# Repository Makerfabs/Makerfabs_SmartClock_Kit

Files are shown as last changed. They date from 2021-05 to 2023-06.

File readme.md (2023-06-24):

# Makerfabs SmartClock Kit

```c++
/*
Version:        V1.2
Author:            Vincent
Create Date:    2021/4/14
Note:
    2023/5/12 V1.2:Change Weather API.
    2021/5/27 V1.1:Add product link and picture.

*/
```

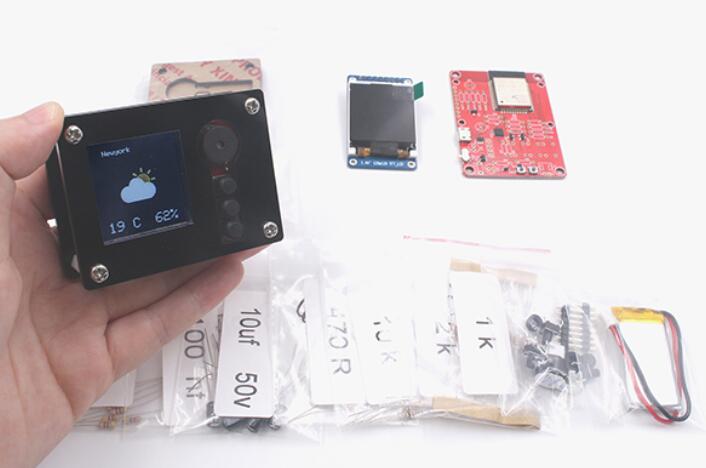
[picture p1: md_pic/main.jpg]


[TOC]

# Makerfabs

[Makerfabs home page](https://www.makerfabs.com/)

[Makerfabs Wiki](https://wiki.makerfabs.com/)

# Makerfabs SmartClock Kit

    It is a kit for starters. After 1~2 hours soldering and assembly, and easy steps to set the WiFi ssid and password by a phone, you will get: 

1. An real-time clock, it will get the world real-time from the Network timing protocol, you can set your local time zone easily 
2. An Alarm clock, with loud noise 
3. An Online world weather forecaster, about the local temperature/weather, you can easily change/alter your address/cities without any re-programming

## Intruduce

Product Link ：[DIY ESP32 SmartClock Kit with Weather Forecasting](https://www.makerfabs.com/diy-esp32-smartclock-kit.html) 

Wiki Link :  [No wiki]() 

Instruction Book : [DIY ESP32 Smart Clock Guide](https://www.makerfabs.com/desfile/files/DIY-ESP32-SmartClock-Guide-V1-5.pdf) 

## Feature

- ESP32 WROOM module: WiFi, Bluetooth, 4MB Flash
- 1.44inch 128*128 color display, ST7735 driver*
- Micro USB interface
- Support Arduino
- 450mAh battery, support charge
- Plug-in components, easy soldering

### Part List

- ESP32 SmartClock Kit Mainboard
- Batch of Capacitors& Resistors/Connectors
- Colorful LCD Module
- Lipo Battery
- Acrylic Boards
- Nuts & screws

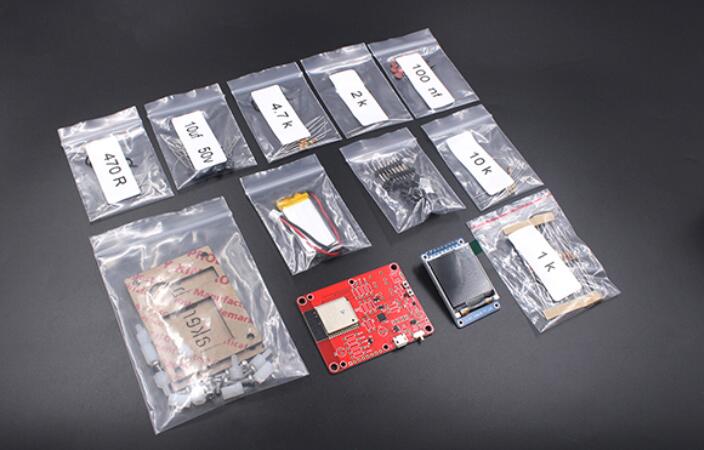
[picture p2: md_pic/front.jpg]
front


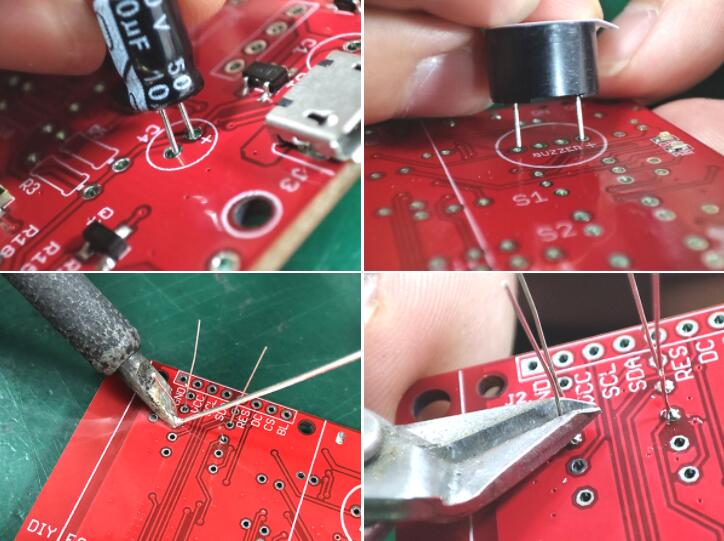
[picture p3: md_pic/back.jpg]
back


# Firmware

## Equipment list

- SmartClock Kit
- Soldering iron

## Compiler Options

**If you have any questions，such as how to install the development board, how to download the code, how to install the library. Please refer to :[Makerfabs_FAQ](https://github.com/Makerfabs/Makerfabs_FAQ)**

- Install board : ESP32 .

- Install library : Adafruit_GFX library.

- Install library : Adafruit_ST7735 library.

- Install library : ArduinoJson library.

- Upload codes, select "ESP32 Dev Module" and "Huge APP"

## How To Use

[How to Make a DIY ESP32 SmartClock with Weather Forecasting](https://www.youtube.com/watch?v=e5g6aSs4Ocg&t=6s)

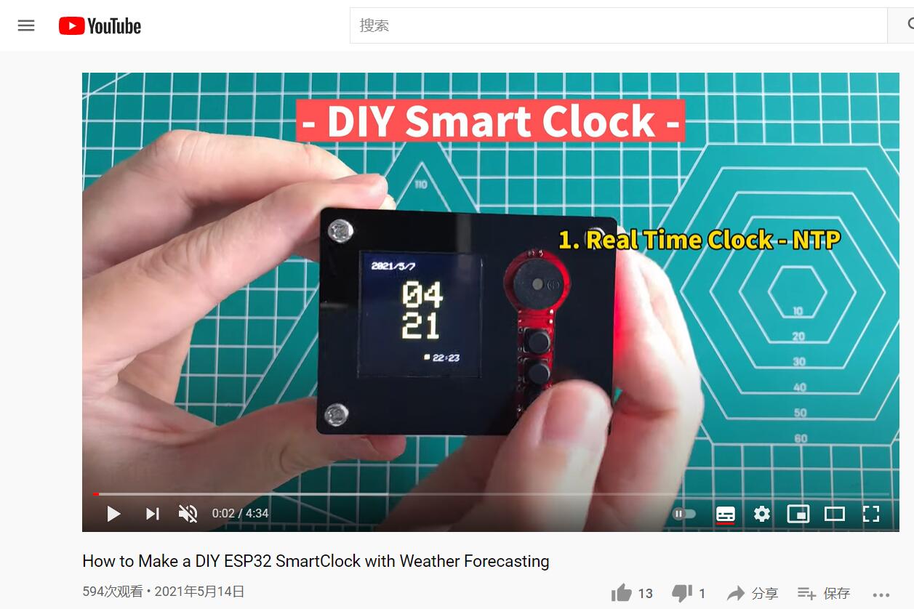
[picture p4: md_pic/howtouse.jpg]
Howtouse


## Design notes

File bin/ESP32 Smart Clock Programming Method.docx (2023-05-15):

# ESP32 Smart Clock Programming Method

Version V1.0

Date 2023/05/15

By LG

Preparing：

1. ESP32 Smartclock Soldered
2. Micro USB 线
3. ESP32 flash Tool flash_download_tool at: https://www.espressif.com/en/support/download/other-tools

Steps：

1. Connect ESP32 Smartclock soldered to PC with USB cable ; power the smartclock on, there should a new device with CP210X bridge port:

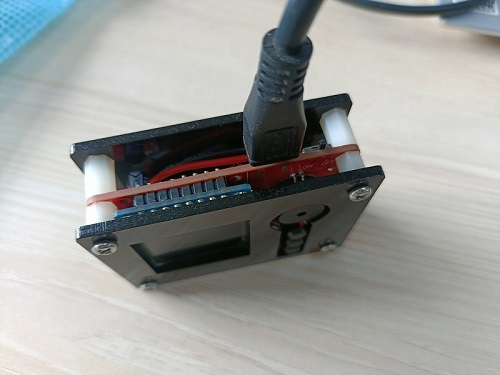
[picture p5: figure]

2. Open the ESP32 flash tool: flash_download_tool_v3.8.5
3. Select Developer Mode-------ESP32 DownloadTool

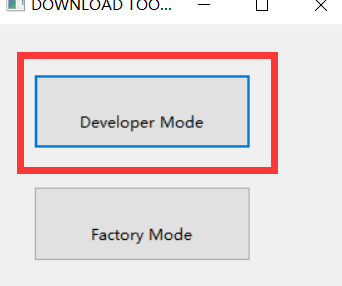
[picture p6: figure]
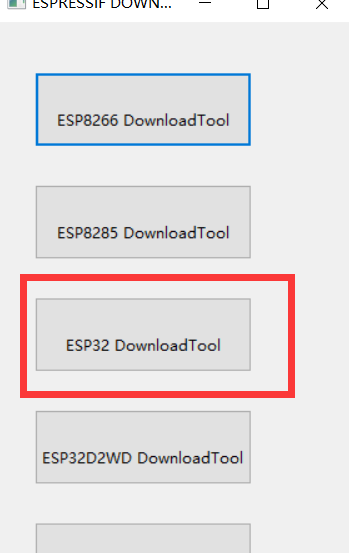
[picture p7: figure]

4. select the related bin files and the related programming address:

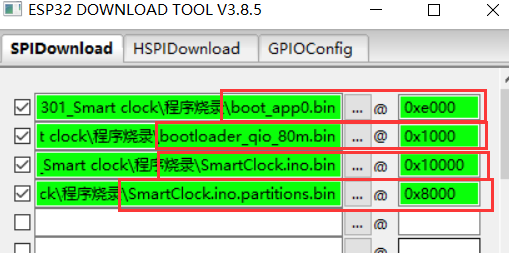
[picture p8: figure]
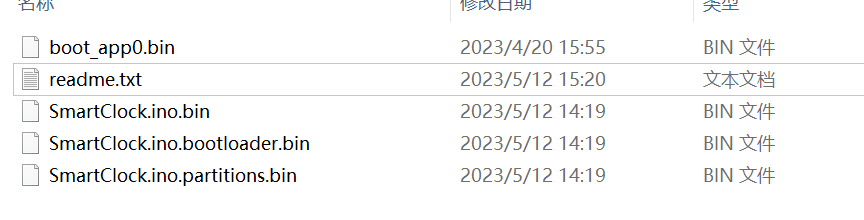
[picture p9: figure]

文件名 | 输入对应地址
boot_app0.bin | 0xe000
SmartClock.ino.bootloader.bin | 0x1000
SmartClock.ino.bin | 0x10000
SmartClock.ino.partitions.bin | 0x8000

5. setting the following specs:

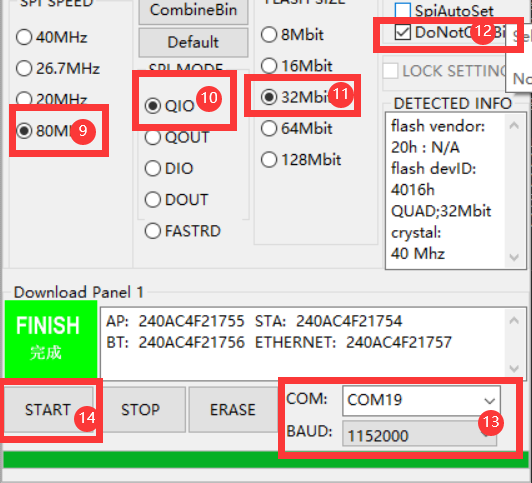
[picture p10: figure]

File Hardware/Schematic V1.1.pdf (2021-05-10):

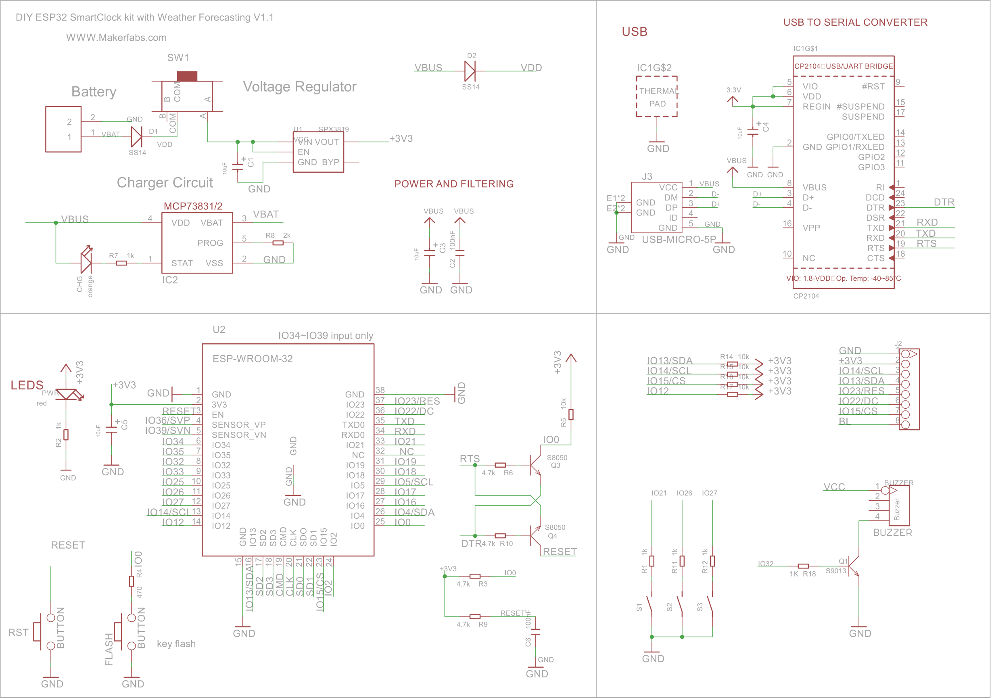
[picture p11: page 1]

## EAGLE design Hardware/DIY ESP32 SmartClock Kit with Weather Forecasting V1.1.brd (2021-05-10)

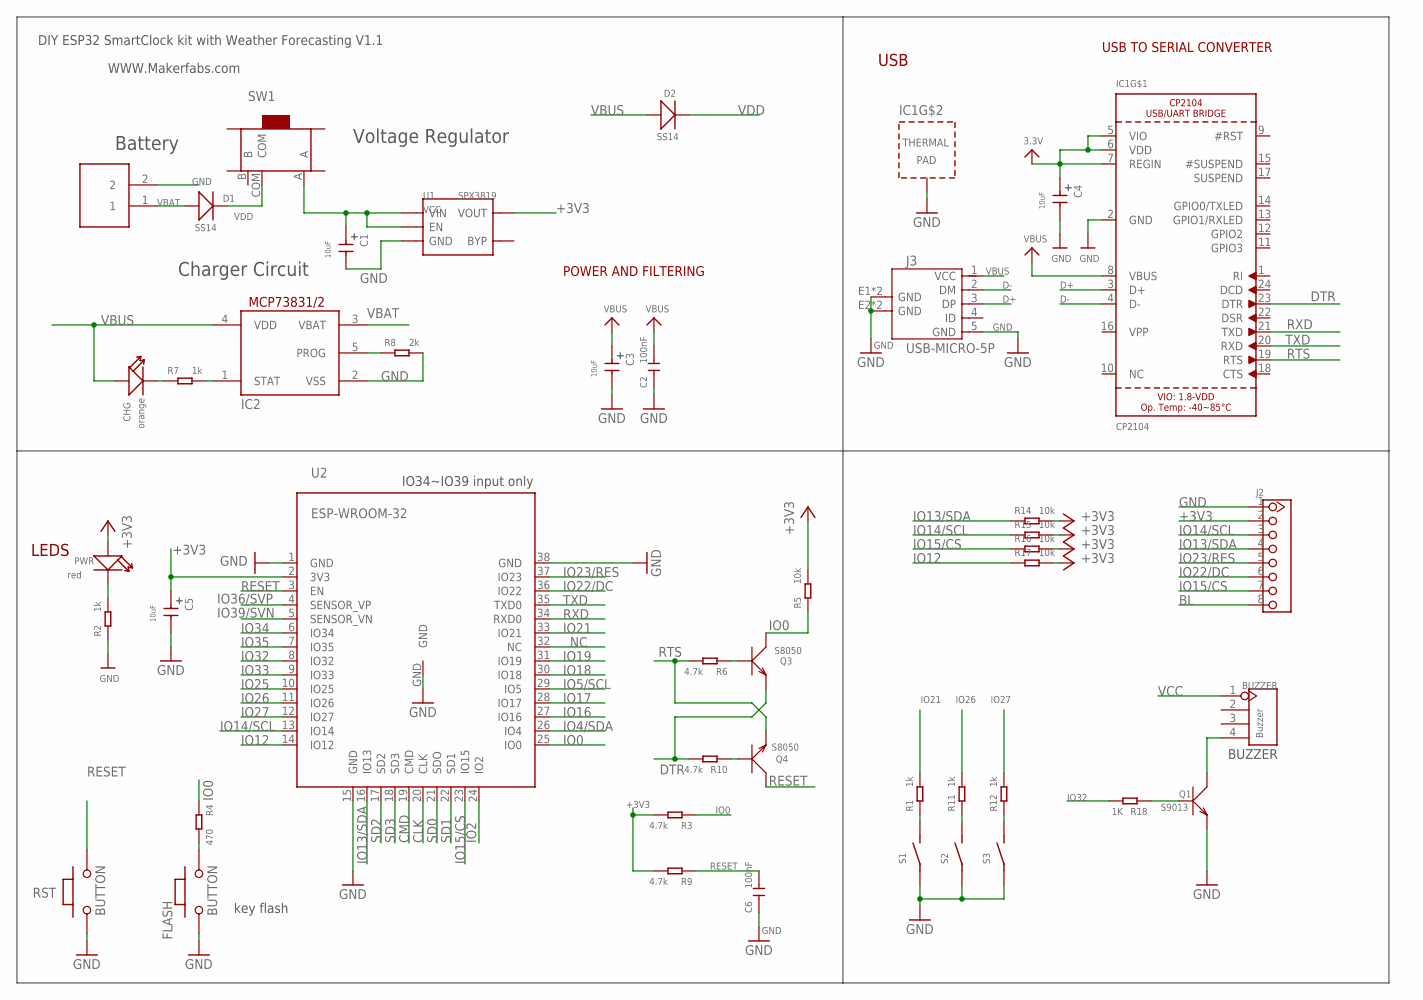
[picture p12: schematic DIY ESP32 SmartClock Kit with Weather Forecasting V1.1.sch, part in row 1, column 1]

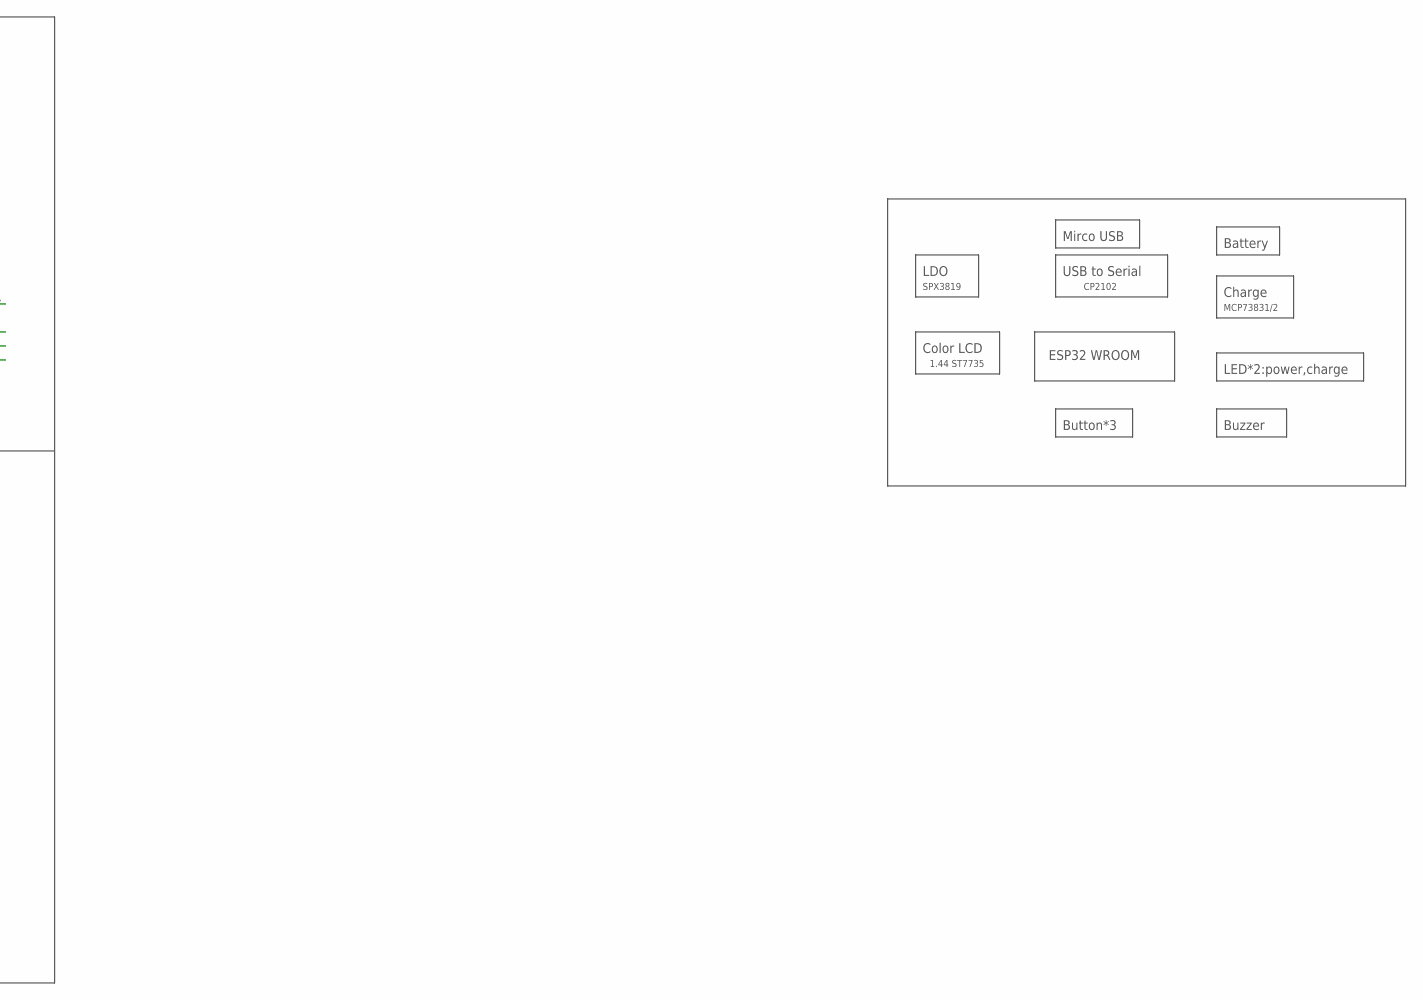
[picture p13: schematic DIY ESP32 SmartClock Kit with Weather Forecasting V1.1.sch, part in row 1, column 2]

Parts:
BUZZER: Buzzer; 4P-65/35ROUND
C1, C3, C4, C5: 10uF; CAP_5*7
C2, C6: 100nF; CERAMIC-5.08
CHG: orange; LED-0603
D1, D2: SS14; SOD323
FLASH: BUTTON; 157SW
IC1: CP2104; QFN24_4MM_SMSC
IC2: MCP73831/OT; SOT23-5L
J1: PH2.0-2P-90-DIP
J2: HEADER-8P-2.54; 8P-2.54
J3: USB-MICRO-5P; MICRO-USB-5P
PWR: red; LED-0603
Q1: S9013; SOT23
Q3, Q4: S8050; SOT23
R1, R2, R7, R11, R12: 1k; 0204/7
R3, R6, R9, R10: 4.7k; 0204/7
R4: 470; 0204/7
R5, R14, R15, R16, R17: 10k; 0204/7
R8: 2k; 0204/7
R18: 1K; 0204/7
RST: BUTTON; 157SW
S1, S2, S3: BUTTON_4.54.5; 3*3_BUTTOM_DIP
SW1: SWITCH-3P-SMD-6.6X2.8; 3P-SMD-2CH-6.6X2.8-REINFORCE
U1: SPX3819; SOT23-5
U2: ESP-WROOM-32

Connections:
+3V3: C4.P$1 (1), C5.P$1 (1), IC1.5 (VIO), IC1.6 (VDD), IC1.7 (REGIN), J2.2, PWR.+, R3.2, R5.2, R9.2, R14.2, R15.2, R16.2, R17.2, U1.5 (VOUT), U2.2 (3V3)
BL: J2.8
CLK: U2.20 (CLK)
CMD: U2.19 (CMD)
D+: IC1.3 (D+), J3.3 (DP)
D-: IC1.4 (D-), J3.2 (DM)
DTR: IC1.23 (DTR), Q3.2 (E), R10.2
GND: C1.P$2 (2), C2.1, C3.P$2 (2), C4.P$2 (2), C5.P$2 (2), C6.1, FLASH.1, IC1.2 (GND), IC1.THERM (TP), IC2.2 (VSS), J1.2, J2.1, J3.5 (GND), J3.E1 (GND), J3.E2 (GND), J3.P1 (GND), J3.P2 (GND), Q1.2 (E), R2.1, R8.2, RST.1, S1.1, S1.2 (1), S2.1, S2.2 (1), S3.1, S3.2 (1), U1.2 (GND), U2.1 (GND), U2.15 (GND), U2.38 (GND), U2.GND
IO0: Q3.3 (C), R3.1, R4.1, R5.1, U2.25 (IO0)
IO2: U2.24 (IO2)
IO4/SDA: U2.26 (IO4)
IO5/SCL: U2.29 (IO5)
IO12: R17.1, U2.14 (IO12)
IO13/SDA: J2.4, R14.1, U2.16 (IO13)
IO14/SCL: J2.3, R15.1, U2.13 (IO14)
IO15/CS: J2.7, R16.1, U2.23 (IO15)
IO16: U2.27 (IO16)
IO17: U2.28 (IO17)
IO18: U2.30 (IO18)
IO19: U2.31 (IO19)
IO21: R1.2, U2.33 (IO21)
IO22/DC: J2.6, U2.36 (IO22)
IO23/RES: J2.5, U2.37 (IO23)
IO25: U2.10 (IO25)
IO26: R11.2, U2.11 (IO26)
IO27: R12.2, U2.12 (IO27)
IO32: R18.2, U2.8 (IO32)
IO33: U2.9 (IO33)
IO34: U2.6 (IO34)
IO35: U2.7 (IO35)
IO36/SVP: U2.4 (SENSOR_VP)
IO39/SVN: U2.5 (SENSOR_VN)
unnamed: R11.1, S2.3, S2.4 (3)
unnamed: BUZZER.4, Q1.3 (C)
unnamed: R12.1, S3.3, S3.4 (3)
unnamed: FLASH.2, R4.2
unnamed: PWR.-, R2.2
unnamed: Q4.1 (B), R10.1
unnamed: Q3.1 (B), R6.1
unnamed: R1.1, S1.3, S1.4 (3)
unnamed: Q1.1 (B), R18.1
unnamed: CHG.-, R7.1
unnamed: IC2.1 (STAT), R7.2
unnamed: IC2.5 (PROG), R8.1
NC: U2.32 (NC)
RESET: C6.2, Q4.3 (C), R9.1, RST.2, U2.3 (EN)
RTS: IC1.19 (RTS), Q4.2 (E), R6.2
RXD: IC1.21 (TXD), U2.34 (RXD0)
SD0: U2.21 (SDO)
SD1: U2.22 (SD1)
SD2: U2.17 (SD2)
SD3: U2.18 (SD3)
TXD: IC1.20 (RXD), U2.35 (TXD0)
VBAT: D1.+, IC2.3 (VBAT), J1.1
VBUS: C2.2, C3.P$1 (1), CHG.+, D2.+, IC1.8 (VBUS), IC2.4 (VDD), J3.1 (VCC)
VCC: BUZZER.1, C1.P$1 (1), SW1.A, U1.1 (VIN), U1.3 (EN)
VDD: D1.-, D2.-, SW1.COM

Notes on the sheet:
USB
LEDS
POWER AND FILTERING
USB TO SERIAL CONVERTER
IO34~IO39 input only
Battery
Voltage Regulator
Charger Circuit
BUZZER
ESP32 WROOM
Mirco USB
Charge
Buzzer
Button*3
LED*2:power,charge
Color LCD
1.44 ST7735
USB to Serial
CP2102
MCP73831/2
LDO
SPX3819
key flash
DIY ESP32 SmartClock kit with Weather Forecasting V1.1
WWW.Makerfabs.com

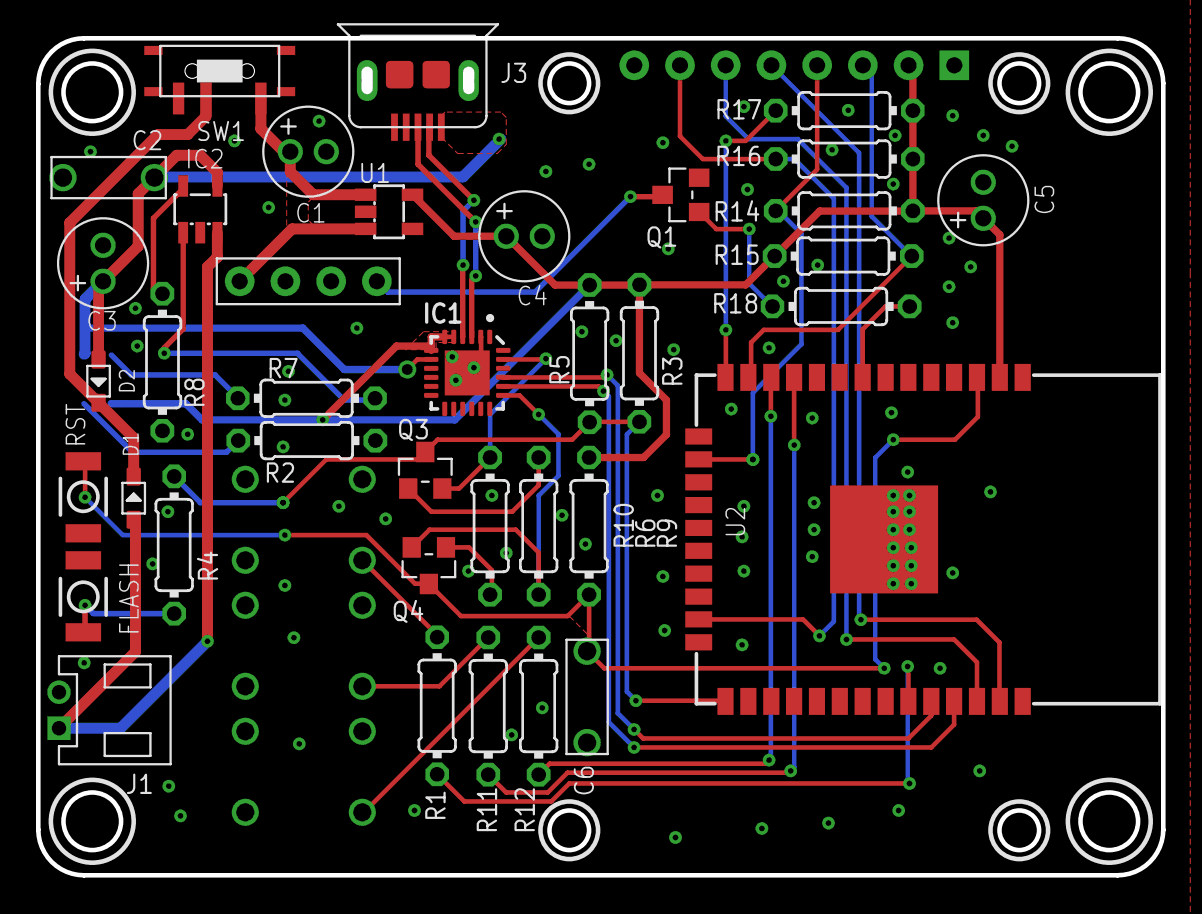
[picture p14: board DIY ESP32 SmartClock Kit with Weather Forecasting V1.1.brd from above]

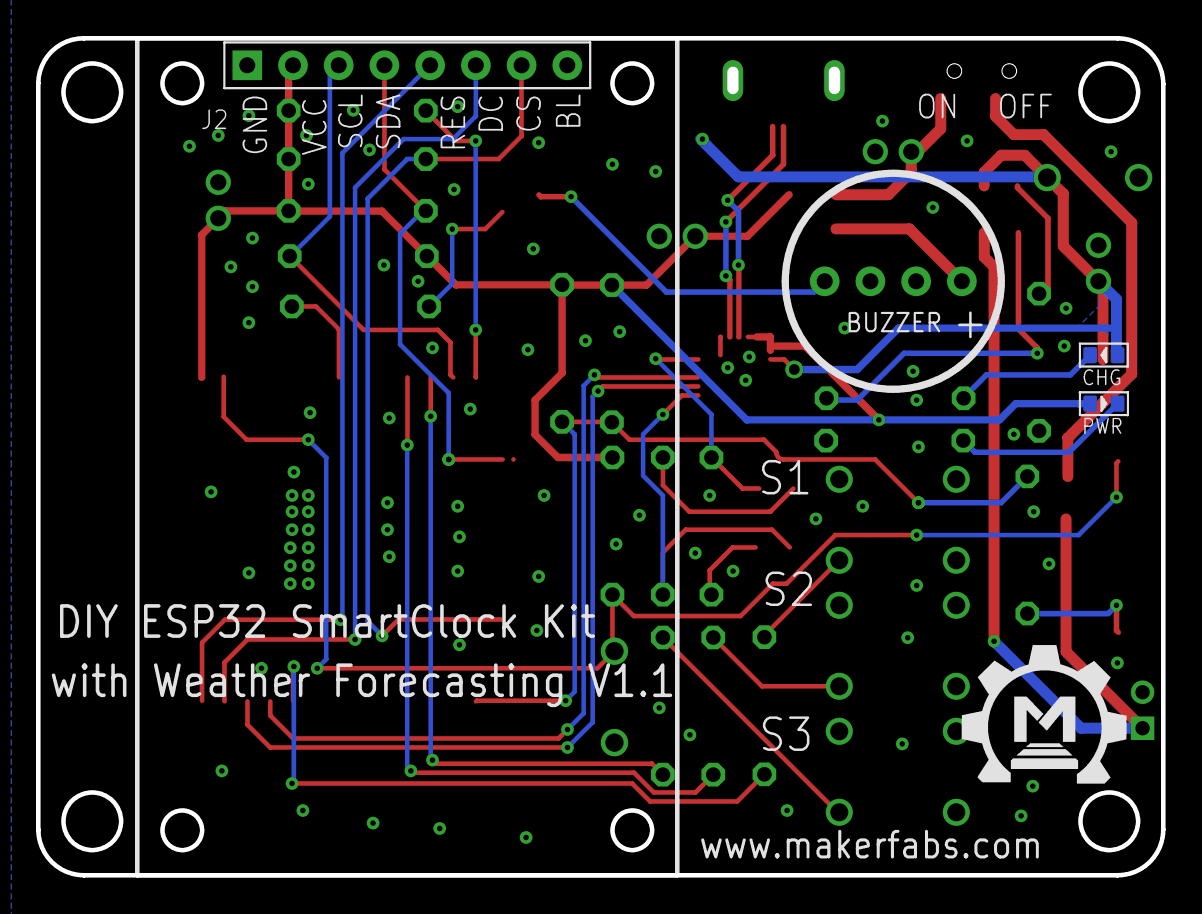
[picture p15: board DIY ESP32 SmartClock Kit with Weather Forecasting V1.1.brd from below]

Board: 2 copper layers, 62.5 x 46.5 mm, 45 parts (4 on the bottom side), 36 nets.

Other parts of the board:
U$1: MAKERFABS_0.3

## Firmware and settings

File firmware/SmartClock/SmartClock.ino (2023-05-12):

#include <Adafruit_GFX.h>    // Core graphics library
#include <Adafruit_ST7735.h> // Hardware-specific library for ST7735
#include <SPI.h>
#include "wifi_save.h"
#include <WiFi.h>
#include "time.h"
#include <ArduinoJson.h>
#include <HTTPClient.h>

#include "a1.h"
#include "sun.h"
#include "rain.h"
#include "cloud.h"
#include "snow.h"

#define BUZZER_PIN 32

#define BUTTON_S WIFI_SET_PIN
#define BUTTON1 26
#define BUTTON2 27

#define TFT_CS 15        // Hallowing display control pins: chip select
#define TFT_RST 23       // Display reset
#define TFT_DC 22        // Display data/command select
#define TFT_BACKLIGHT -1 // Display backlight pin

#define TFT_MOSI 13 // Data out
#define TFT_SCLK 14 // Clock out

Adafruit_ST7735 tft = Adafruit_ST7735(TFT_CS, TFT_DC, TFT_MOSI, TFT_SCLK, TFT_RST);

const char *ntpServer = "120.25.108.11";
const long gmtOffset_sec = (-5) * 60 * 60; // China+8
const int daylightOffset_sec = 0;

struct tm timeinfo;
const int page_num = 4;
int page = 0;
int page_line = 0;
int page_add = 0;
int16_t alarm_h = 8;
int16_t alarm_m = 0;
int16_t timezone = 0;
int alarm_flag = 0;
int alarm_enable = 1;
int last_h = -1;
int last_m = -1;
long int weather_runtime = -600000;
int button_flag = 0;
int location_index = 0;

String weather_location[] = {"Washington", "London", "Beijing", "Paris"};
String timezone_city[24] = {"-11", "-10", "-9", "Vancouver", "-7", "Chicago", "Washington", "-4", "-3", "-2", "-1", "London", "Paris", "Athens", "Moscow", "4", "New Delhi", "Bangladesh", "Bangkok", "Beijing", "Tokyo", "10", "11", "12"};

void setup(void)
{

    Serial.begin(115200);
    Serial.print(F("Hello! Makerfabs Smartclock Kit"));

    pin_init();
    tft_init();
    congfig_init();
    wifi_init();

    tft.setCursor(0, 110);
    tft.print("All init over");
    delay(2000);

    tft.fillScreen(ST77XX_BLACK);

    // Show logo
    tft.drawRGBBitmap(0, 0, a1, 128, 128);
    delay(1000);
}

void loop()
{
    main_menu();
}

// Init

void pin_init()
{
    Serial.println("Start PIN init");

    pinMode(BUZZER_PIN, OUTPUT);
    pinMode(BUTTON_S, INPUT_PULLUP);
    pinMode(BUTTON1, INPUT_PULLUP);
    pinMode(BUTTON2, INPUT_PULLUP);

    /*
    digitalWrite(BUZZER_PIN, HIGH);
    delay(500);
    digitalWrite(BUZZER_PIN, LOW);
    */

    Serial.println("PIN init done");
    delay(100);
}

void tft_init()
{
    Serial.println("Start TFT init");

    tft.initR(INITR_144GREENTAB);
    tft.fillScreen(ST77XX_BLACK);
    delay(100);

    Serial.println("TFT init done");
    delay(100);

    tft.setCursor(0, 0);
    tft.setTextColor(ST77XX_WHITE);
    tft.setTextSize(1);
    tft.print("TFT init over");
}

void wifi_init()
{
    Serial.println("Start WIFI config and ntp init");
    tft.fillScreen(ST77XX_BLACK);

    tft.setCursor(0, 10);
    tft.print("WIFI init start");

    tft.setCursor(0, 30);
    tft.print("If you want set WIFI. Hold down S1 button 3 second, then clock will go into Settings Mode. Use your phone connect to Makerfabs_ap, and visit \"192.168.4.1\".");

    if (wifi_set_main())
    {
        tft.fillRect(0, 20, 128, 128, ST77XX_BLACK);
        Serial.println("Connect WIFI SUCCESS");
        tft.setCursor(0, 50);
        tft.print("Connect WIFI SUCCESS");
    }
    else
    {
        tft.fillRect(0, 30, 128, 100, ST77XX_BLACK);
        Serial.println("Connect WIFI FAULT");
        tft.setCursor(0, 50);
        tft.print("Connect WIFI FAULT");
    }

    // configTime(gmtOffset_sec, daylightOffset_sec, ntpServer);
    configTime((const long)(timezone * 3600), daylightOffset_sec, ntpServer);
    Serial.println(F("Alread get npt time."));
    tft.setCursor(0, 100);
    tft.print("Alread get npt time");
}

void congfig_init()
{
    read_congfig(&alarm_h, &alarm_m, &timezone);
    tft.setCursor(10, 10);
    tft.print("Alread get congfig");
    delay(500);
}

// Menu

void main_menu()
{
    if (!getLocalTime(&timeinfo))
    {
        Serial.println("Failed to obtain time");
    }

    switch (page)
    {
    case 0:
        clock_page();
        break;
    case 1:
        alarm_page();
        break;
    case 2:
        timezone_page();
        break;
    case 3:
        weather_page();
        // weather_request();
        break;

    default:
        break;
    }

    // Check alarm clock
    if (timeinfo.tm_hour == alarm_h && timeinfo.tm_min == alarm_m && alarm_enable == 1)
    {
        if (alarm_flag == 0)
            alarming();
        alarm_flag = 1;
    }
    else
    {
        alarm_flag = 0;
    }

    // Check Button Status in 10s
    int runtime = millis();
    while (millis() - runtime < 10000)
    {
        if (digitalRead(BUTTON_S) == LOW)
        {
            delay(40);
            if (digitalRead(BUTTON_S) == LOW)
            {
                button_flag = 1;
                page = ++page % page_num;
                page_line = 0;
                page_add = 0;

                break;
            }
        }

        if (digitalRead(BUTTON1) == LOW)
        {
            delay(40);
            if (digitalRead(BUTTON1) == LOW)
            {
                button_flag = 1;
                page_line++;
                break;
            }
        }

        if (digitalRead(BUTTON2) == LOW)
        {
            delay(40);
            if (digitalRead(BUTTON2) == LOW)
            {
                button_flag = 1;
                page_add++;
                break;
            }
        }

        delay(100);
    }
}

void clock_page()
{
    // If minute wasn't change,don't flesh screen
    if (last_h == timeinfo.tm_hour && last_m == timeinfo.tm_min && button_flag == 0)
        return;
    else
    {
        button_flag = 0;
        last_h = timeinfo.tm_hour;
        last_m = timeinfo.tm_min;
    }
    tft.fillScreen(ST77XX_BLACK);

    String date_str = (String)(timeinfo.tm_year + 1900) + "/" + (String)(timeinfo.tm_mon + 1) + "/" + (String)(timeinfo.tm_mday);

    tft.setTextColor(ST77XX_WHITE);
    tft.setTextSize(1);
    tft.setCursor(10, 10);
    tft.print(date_str);

    // Check weather alarm enable set
    if (page_add == 1)
    {
        page_add = 0;
        alarm_enable = (alarm_enable + 1) % 2;
    }

    // Check alarm enable display
    if (alarm_enable)
    {
        tft.fillRect(70, 110, 5, 5, ST77XX_YELLOW);
    }
    else
    {
        tft.fillRect(70, 110, 5, 5, ST77XX_BLACK);
    }

    // Config display
    tft.setCursor(80, 110);
    String alarm_str = "";
    alarm_h < 10 ? alarm_str += "0" : alarm_str += "";
    alarm_str += (String)alarm_h + ":";
    alarm_m < 10 ? alarm_str += "0" : alarm_str += "";
    alarm_str += (String)alarm_m;
    tft.print(alarm_str);

    // Clock display
    tft.setCursor(45, 30);
    tft.setTextColor(ST77XX_YELLOW);
    tft.setTextSize(4);

    if (timeinfo.tm_hour < 10)
        tft.print("0");
    tft.print(timeinfo.tm_hour);
    tft.setCursor(45, 64);
    if (timeinfo.tm_min < 10)
        tft.print("0");
    tft.print(timeinfo.tm_min);
}

void weather_page()
{
    // Every ten minutes requst.
    if (millis() - weather_runtime < 600000 && button_flag == 0)
        return;
    else
    {
        if (page_add == 1)
        {
            page_add = 0;
            location_index = (location_index + 1) % 4;
        }
        button_flag = 0;
        weather_runtime = millis();
    }

    tft.fillScreen(ST77XX_BLACK);
    tft.setCursor(0, 10);
    tft.setTextColor(ST77XX_WHITE);
    tft.setTextSize(1);
    tft.print("Get the weather online");

    tft.setCursor(0, 40);
    tft.print("Waiting ... ...");

    weather_request();
}

void alarm_page()
{
    tft.fillScreen(ST77XX_BLACK);

    tft.setCursor(10, 10);
    tft.setTextColor(ST77XX_WHITE);
    tft.setTextSize(2);
    tft.print("ALARM SET");

    // Check button action, set alarm time.
    if (page_line % 2 == 0)
    {
        tft.fillCircle(35, 40, 4, ST77XX_WHITE);
        if (page_add != 0)
        {
            page_add = 0;
            alarm_h = ++alarm_h % 24;
            record_alarm(alarm_h, alarm_m);
        }
    }
    else
    {
        tft.fillCircle(35, 74, 4, ST77XX_WHITE);
        if (page_add != 0)
        {
            page_add = 0;
            alarm_m = ++alarm_m % 60;
            record_alarm(alarm_h, alarm_m);
        }
    }

    tft.setCursor(45, 30);
    tft.setTextColor(ST77XX_YELLOW);
    tft.setTextSize(4);
    if (alarm_h < 10)
        tft.print("0");
    tft.print(alarm_h);
    tft.setCursor(45, 64);
    if (alarm_m < 10)
        tft.print("0");
    tft.print(alarm_m);
}

void timezone_page()
{
    tft.fillScreen(ST77XX_BLACK);

    tft.setCursor(10, 10);
    tft.setTextColor(ST77XX_WHITE);
    tft.setTextSize(2);
    tft.print("TIMEZONE");

    tft.setCursor(0, 30);
    tft.setTextColor(ST77XX_WHITE);
    tft.setTextSize(1);
    tft.print("Effective after rst");
    if (page_add != 0)
    {
        page_add = 0;
        timezone = ++timezone;
        if (timezone > 12)
            timezone = -11;
        record_timezone(timezone);
    }

    tft.setCursor(30, 60);
    tft.setTextColor(ST77XX_YELLOW);
    tft.setTextSize(4);
    if (timezone >= 0)
        tft.print("+");
    tft.print(timezone);

    tft.setCursor(20, 90);
    tft.setTextColor(ST77XX_YELLOW);
    tft.setTextSize(1);
    // tft.print(timezone_city[timezone + 11]);
}

// Functions
void weather_request()
{
    HTTPClient http;
    String text = "";

    Serial.print("[HTTP] begin...\n");

    String url = "http://api.weatherapi.com/v1/current.json?key=271578bfbe12438085782536232404&q=" + weather_location[location_index] + "&aqi=no";

    Serial.println(url);

    http.begin(url);

    Serial.print("[HTTP] GET...\n");
    // start connection and send HTTP header
    int httpCode = http.GET();

    // httpCode will be negative on error
    if (httpCode > 0)
    {
        // HTTP header has been send and Server response header has been handled
        Serial.printf("[HTTP] GET... code: %d\n", httpCode);

        // file found at server
        if (httpCode == HTTP_CODE_OK)
        {
            String payload = http.getString();
            Serial.println(payload);

            // JSON
            DynamicJsonDocument doc(1024);
            deserializeJson(doc, payload);
            JsonObject obj = doc.as<JsonObject>();

            int cond_num = doc["current"]["condition"]["code"];
            String cond_txt = doc["current"]["condition"]["text"];
            int tmp = doc["current"]["temp_c"];
            int hum = doc["current"]["humidity"];
            String wind_dir = doc["current"]["wind_dir"];

            weather_show(cond_num, tmp, hum);
            text = weather_location[location_index] + cond_txt + ", " + tmp + " centigrade, " + wind_dir + " wind,relative humidity " + hum + " percent.";
            Serial.println(text);
        }
    }
    else
    {
        Serial.printf("[HTTP] GET... failed, error: %s\n", http.errorToString(httpCode).c_str());
    }

    http.end();
}

void weather_show(int cond_num, int temperature, int hum)
{
    tft.fillScreen(ST77XX_BLACK);

    tft.setTextColor(ST77XX_WHITE);
    tft.setTextSize(1);
    tft.setCursor(20, 10);
    tft.print(weather_location[location_index]);

    Serial.printf("cond_code: %d\n", cond_num);

    // The weather code is in https://www.weatherapi.com/docs/conditions.json
    if (cond_num == 1000) // sun
        tft.drawRGBBitmap(32, 32, sun, 64, 64);
    else if (cond_num > 1000 && cond_num <= 1147) // cloud
        tft.drawRGBBitmap(32, 32, cloud, 64, 64);
    else if (cond_num > 1147 && cond_num < 1204) // rain
        tft.drawRGBBitmap(32, 32, rain, 64, 64);
    else if (cond_num >= 1204 && cond_num < 1282) // snow
        tft.drawRGBBitmap(32, 32, snow, 64, 64);
    else
    {
        tft.setTextColor(ST77XX_RED);
        tft.setTextSize(2);
        tft.setCursor(20, 60);
        tft.print("No Icon");
    }

    tft.setTextColor(ST77XX_WHITE);
    tft.setTextSize(2);

    tft.setCursor(10, 110);
    tft.print(temperature);
    tft.print(" C");

    tft.setCursor(80, 110);
    tft.print(hum);
    tft.print("%");
}

void alarming()
{
    int flag = 0;
    int runtime = millis();

    while (1)
    {

        if (millis() - runtime > 1000)
        {
            runtime = millis();
            if (flag % 2 == 0)
            {
                tft.fillRect(0, 0, 128, 24, ST77XX_RED);
                tft.fillRect(0, 104, 128, 24, ST77XX_YELLOW);
                digitalWrite(BUZZER_PIN, HIGH);
            }
            else
            {
                digitalWrite(BUZZER_PIN, LOW);
                tft.fillRect(0, 0, 128, 24, ST77XX_YELLOW);
                tft.fillRect(0, 104, 128, 24, ST77XX_RED);
            }
            flag++;
        }
        if (digitalRead(BUTTON_S) == LOW)
        {
            break;
        }

        if (digitalRead(BUTTON1) == LOW)
        {
            break;
        }

        if (digitalRead(BUTTON2) == LOW)
        {
            break;
        }
        delay(10);
    }

    digitalWrite(BUZZER_PIN, LOW);
}

void record_alarm(int16_t hour, int16_t minute)
{

    // 初始化NVS，并检查初始化情况
    esp_err_t err = nvs_flash_init();
    if (err == ESP_ERR_NVS_NO_FREE_PAGES || err == ESP_ERR_NVS_NEW_VERSION_FOUND)
    {
        // 如果NVS分区被占用则对其进行擦除
        // 并再次初始化
        ESP_ERROR_CHECK(nvs_flash_erase());
        err = nvs_flash_init();
    }
    ESP_ERROR_CHECK(err);

    // Open 打开NVS文件
    printf("\n");
    printf("Opening Non-Volatile Config (NVS) handle... ");
    nvs_handle my_handle;                                // 定义不透明句柄
    err = nvs_open("Config", NVS_READWRITE, &my_handle); // 打开文件
    if (err != ESP_OK)
    {
        printf("Error (%s) opening NVS handle!\n", esp_err_to_name(err));
    }
    else
    {
        printf("Done\n");

        // Write
        printf("Updating alarm_h in NVS ... ");
        err = nvs_set_i16(my_handle, "alarm_h", hour);
        printf((err != ESP_OK) ? "Failed!\n" : "Done\n");

        printf("Updating alarm_m in NVS ... ");
        err = nvs_set_i16(my_handle, "alarm_m", minute);
        printf((err != ESP_OK) ? "Failed!\n" : "Done\n");

        // Commit written value.
        // After setting any values, nvs_commit() must be called to ensure changes are written
        // to flash storage. Implementations may write to storage at other times,
        // but this is not guaranteed.
        printf("Committing updates in NVS ... ");
        err = nvs_commit(my_handle);
        printf((err != ESP_OK) ? "Failed!\n" : "Done\n");

        // Close
        nvs_close(my_handle);
    }

    printf("\n");
}

void record_timezone(int16_t timezone)
{

    // 初始化NVS，并检查初始化情况
    esp_err_t err = nvs_flash_init();
    if (err == ESP_ERR_NVS_NO_FREE_PAGES || err == ESP_ERR_NVS_NEW_VERSION_FOUND)
    {
        // 如果NVS分区被占用则对其进行擦除
        // 并再次初始化
        ESP_ERROR_CHECK(nvs_flash_erase());
        err = nvs_flash_init();
    }
    ESP_ERROR_CHECK(err);

    // Open 打开NVS文件
    printf("\n");
    printf("Opening Non-Volatile Config (NVS) handle... ");
    nvs_handle my_handle;                                // 定义不透明句柄
    err = nvs_open("Config", NVS_READWRITE, &my_handle); // 打开文件
    if (err != ESP_OK)
    {
        printf("Error (%s) opening NVS handle!\n", esp_err_to_name(err));
    }
    else
    {
        printf("Done\n");

        // Write
        printf("Updating alarm_h in NVS ... ");
        err = nvs_set_i16(my_handle, "timezone", timezone);
        printf((err != ESP_OK) ? "Failed!\n" : "Done\n");

        printf("Committing updates in NVS ... ");
        err = nvs_commit(my_handle);
        printf((err != ESP_OK) ? "Failed!\n" : "Done\n");

        // Close
        nvs_close(my_handle);
    }

    printf("\n");
}

void read_congfig(int16_t *hour, int16_t *minute, int16_t *timezone)
{
    // 初始化NVS，并检查初始化情况
    esp_err_t err = nvs_flash_init();
    if (err == ESP_ERR_NVS_NO_FREE_PAGES || err == ESP_ERR_NVS_NEW_VERSION_FOUND)
    {
        // 如果NVS分区被占用则对其进行擦除
        // 并再次初始化
        ESP_ERROR_CHECK(nvs_flash_erase());
        err = nvs_flash_init();
    }
    ESP_ERROR_CHECK(err);

    // Open 打开NVS文件
    printf("\n");
    printf("Opening Non-Volatile Config (NVS) handle... ");
    nvs_handle my_handle;                                // 定义不透明句柄
    err = nvs_open("Config", NVS_READWRITE, &my_handle); // 打开文件
    if (err != ESP_OK)
    {
        printf("Error (%s) opening NVS handle!\n", esp_err_to_name(err));
    }
    else
    {
        printf("Done\n");

        // Read
        printf("Reading Config from NVS ... \n");

        // Read alarm_h
        err = nvs_get_i16(my_handle, "alarm_h", hour);
        switch (err)
        {
        case ESP_OK:
            printf("Done\n");
            printf("alarm_h: %d\n", *hour);
            break;
        case ESP_ERR_NVS_NOT_FOUND:
            printf("The value is not initialized yet!\n");
            break;
        default:
            printf("Error (%s) reading!\n", esp_err_to_name(err));
        }

        // Read alarm_m
        err = nvs_get_i16(my_handle, "alarm_m", minute);
        switch (err)
        {
        case ESP_OK:
            printf("Done\n");
            printf("alarm_m: %d\n", *minute);
            break;
        case ESP_ERR_NVS_NOT_FOUND:
            printf("The value is not initialized yet!\n");
            break;
        default:
            printf("Error (%s) reading!\n", esp_err_to_name(err));
        }

        // Read timezone
        err = nvs_get_i16(my_handle, "timezone", timezone);
        switch (err)
        {
        case ESP_OK:
            printf("Done\n");
            printf("timezone: %d\n", *timezone);
            break;
        case ESP_ERR_NVS_NOT_FOUND:
            printf("The value is not initialized yet!\n");
            break;
        default:
            printf("Error (%s) reading!\n", esp_err_to_name(err));
        }

        // Close
        nvs_close(my_handle);
    }

    printf("\n");
    return;
}

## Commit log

2021-05-08 create sch pcb
    [DIY ESP32 SmartClock Kit with Weather Forecasting V1.1.brd, DIY ESP32 SmartClock Kit with Weather Forecasting V1.1.sch]
2023-05-15 Create ESP32 Smart Clock Programming Method.docx

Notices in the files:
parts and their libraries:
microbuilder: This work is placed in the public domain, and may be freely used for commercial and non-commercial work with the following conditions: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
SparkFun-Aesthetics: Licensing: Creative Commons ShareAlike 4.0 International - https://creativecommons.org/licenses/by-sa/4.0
